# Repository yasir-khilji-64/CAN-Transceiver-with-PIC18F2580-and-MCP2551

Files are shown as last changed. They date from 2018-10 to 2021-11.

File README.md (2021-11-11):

# CAN Transceiver with PIC18F2580 and MCP2551

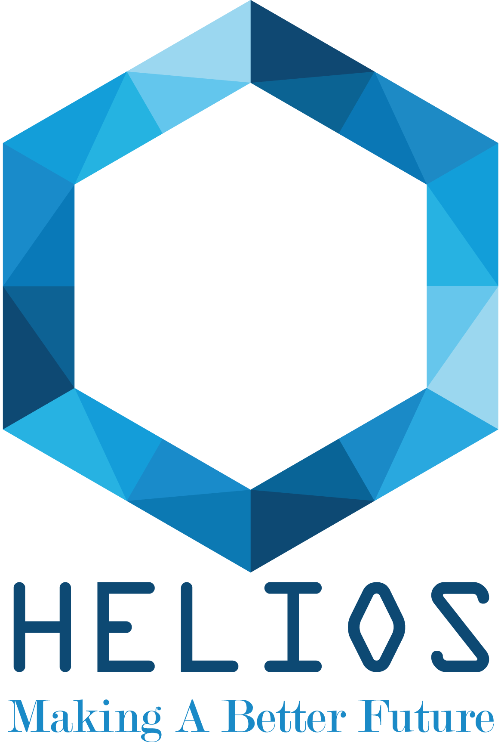
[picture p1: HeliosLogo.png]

<h2 align="center"><strong>Developed by Helios LLC</strong></h2>

## Development
Current version is **v2.0**. The device uses **PIC18F25K80** as the base MCU. Other chips include **MCP2551 High-Speed CAN Transceiver**. Board is developed for students who are learning Electronics Design and PCB Design. 

---
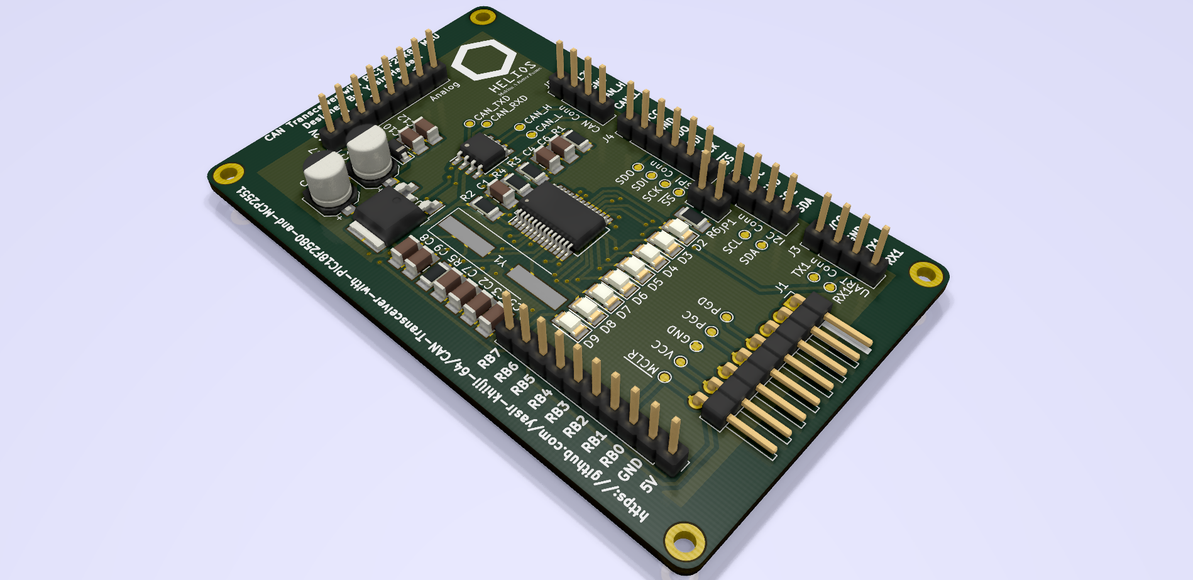
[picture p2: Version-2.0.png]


## Built With
* [KiCad 5.0](http://kicad.org) - PCB Design Tool

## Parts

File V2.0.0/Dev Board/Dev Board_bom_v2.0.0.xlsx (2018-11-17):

Component | Description | Part | References | Value | Footprint | Quantity Per PCB | Quantity Per Board | Price | Datasheet | Supplier-I Part # | Mfr | Mfr Part # | Supplier-I
1 | Unpolarized capacitor | C | C1 C2 C3 C5 C10 C12 | 100nF | C_1206_3216Metric_Pad1.39x1.80mm_HandSolder | 6 | 120 | SEK 386.40 | ~ | 2332842 | AVX | 12061C104JAT2A | Farnell
2 | Polarised capacitor | CP | C11 C13 | 100uF | CP_Elec_5x5.9 | 2 | 40 | SEK 158.80 | ~ | 2065969 | Panasonic Electronic Components | EEE-FT1C101AR | Farnell
3 | Unpolarized capacitor | C | C7 | 10uF | C_1206_3216Metric_Pad1.39x1.80mm_HandSolder | 1 | 20 | SEK 91.20 | ~ | 3188954 | Yageo | CC1206ZRY5V6BB106 | Farnell
4 | Unpolarized capacitor | C | C8 C9 | 22pF | C_1206_3216Metric_Pad1.39x1.80mm_HandSolder | 2 | 40 | SEK 52.00 | ~ | 2812188 | Wurth Electronics Inc. | 885012008011 | Farnell
5 | Unpolarized capacitor | C | C4 C6 | 560pF | C_1206_3216Metric_Pad1.39x1.80mm_HandSolder | 2 | 40 | SEK 101.60 | ~ | 2211027 | Yageo | CC1206JKNPOZBN561 | Farnell
6 | LED generic | LED | D2 D3 D4 D5 D6 D7 D8 D9 | Green | LED_1206_3216Metric_Pad1.22x1.80mm_HandSolder | 8 | 160 | SEK 241.60 | ~ | 8554595 | BROADCOM LIMITED | HSMG-C150. | Farnell
7 | Schottky diode | D_Schottky | D1 | MBR0530 | D_SOD-123 | 1 | 20 | SEK 50.60 | ~ | 2463401 | ON SEMICONDUCTOR | MBR0530 | Farnell
8 | Generic connector, single row, 01x08, script generated (kicad-library-utils/schlib/autogen/connector/) | Conn_01x08 | J7 | Analog | PinHeader_1x08_P2.54mm_Vertical | 1 | 20 | SEK 67.80 | ~ | 2356160 | WURTH ELEKTRONIK | 61300811121 | Farnell
9 | Generic connector, single row, 01x04, script generated (kicad-library-utils/schlib/autogen/connector/) | Conn_01x04 | J5 | CAN Conn | PinHeader_1x04_P2.54mm_Vertical | 1 | 20 | SEK 22.00 | ~ | 1022250 | HARWIN | M20-9990445 | Farnell
10 | Generic connector, single row, 01x04, script generated (kicad-library-utils/schlib/autogen/connector/) | Conn_01x04 | J2 | I2C Conn | PinHeader_1x04_P2.54mm_Vertical | 1 | 20 | SEK 22.00 | ~ | 1022250 | HARWIN | M20-9990445 | Farnell
11 | Generic connector, single row, 01x08, script generated (kicad-library-utils/schlib/autogen/connector/) | Conn_01x08 | J1 | PICKIT4 Conn | PinHeader_1x08_P2.54mm_Horizontal | 1 | 20 | SEK 142.60 | ~ | 2356183 | WURTH ELEKTRONIK | 61300811021 | Farnell
12 | Generic connector, single row, 01x10, script generated (kicad-library-utils/schlib/autogen/connector/) | Conn_01x10 | J6 | PORT B | PinHeader_1x10_P2.54mm_Vertical | 1 | 20 | SEK 166.80 | ~ | 1841229 | WURTH ELEKTRONIK | 61301011121 | Farnell
13 | Generic connector, single row, 01x06, script generated (kicad-library-utils/schlib/autogen/connector/) | Conn_01x06 | J4 | SPI Conn | PinHeader_1x06_P2.54mm_Vertical | 1 | 20 | SEK 61.20 | ~ | 2356158 | WURTH ELEKTRONIK | 61300611121 | Farnell
14 | Generic connector, single row, 01x04, script generated (kicad-library-utils/schlib/autogen/connector/) | Conn_01x04 | J3 | UART Conn | PinHeader_1x04_P2.54mm_Vertical | 1 | 20 | SEK 22.00 | ~ | 1022250 | HARWIN | M20-9990445 | Farnell
15 | Jumper, normally closed | Jumper_NC_Small | JP1 | JP_LED | PinHeader_1x02_P2.54mm_Vertical | 1 | 20 | SEK 26.40 | ~ | 9731075 | MOLEX | 22-03-2021 | Farnell
16 | Resistor | R | R3 R4 | 100 | R_1206_3216Metric_Pad1.39x1.80mm_HandSolder | 2 | 40 | SEK 28.48 | ~ | 9240888 | Yageo | RC1206FR-07100RL | Farnell
17 | Resistor | R | R2 | 10k | R_1206_3216Metric_Pad1.39x1.80mm_HandSolder | 1 | 20 | SEK 274.80 | ~ | 1653333 | VISHAY | TNPW120610K0BEEA | Farnell
18 | Resistor | R | R5 | 1M | R_1206_3216Metric_Pad1.39x1.80mm_HandSolder | 1 | 20 | SEK 8.68 | ~ | 1469968 | VISHAY | CRCW12061M00FKEA | Farnell
19 | Resistor | R | R6 | 330 | R_1206_3216Metric_Pad1.39x1.80mm_HandSolder | 1 | 20 | SEK 16.76 | ~ | 9240918 | Yageo | RC1206FR-07330RL | Farnell
20 | Resistor | R | R1 | 4.7k | R_1206_3216Metric_Pad1.39x1.80mm_HandSolder | 1 | 20 | SEK 42.20 | ~ | 2470962 | Bourns Inc. | CRS1206-FX-4701ELF | Farnell
21 | High-Speed CAN Transceiver, 1Mbps, 5V supply, SOIC8 package | MCP2551-I-SN | U1 | MCP2551-I-SN | SOIC-8_3.9x4.9mm_P1.27mm | 1 | 20 | SEK 183.80 | http://ww1.microchip.com/downloads/en/devicedoc/21667d.pdf | 9758569 | Microchip Technology | MCP2551-I/SN | Farnell
22 | 1A Low drop-out regulator, Fixed Output 12V, TO-252 (DPAK) | NCP1117-5.0_TO252 | U3 | NCP1117-5.0_TO252 | TO-252-2 | 1 | 20 | SEK 68.60 | http://www.onsemi.com/pub_link/Collateral/NCP1117-D.PDF | 2296057 | ON SEMICONDUCTOR | NCP1117DT50G | Farnell
23 | 32K Flash, 3.5K RAM, 1K EEPROM, PIC18 Microcontroller ADC PWM CAN SPI I2C USART in SSOP28 package | PIC18F25K80_ISS | U2 | PIC18F25K80_ISS | SSOP-28_5.3x10.2mm_P0.65mm | 1 | 20 | SEK 890.60 | http://ww1.microchip.com/downloads/en/DeviceDoc/39977f.pdf | 9321284 | Microchip Technology | PIC18F2580-I/SO | Farnell
24 | Two pin crystal | Crystal | Y1 | 20MHz | Crystal_SMD_HC49-SD_HandSoldering | 1 | 20 | SEK 59.20 | ~ | 2467724 | Abracon LLC | ABLS-20.000MHZ-B2-T | Farnell
25 | Jumper | - | - | - | - | 1 | 20 | SEK 64.00 | - | 1822046 | TE CONNECTIVITY | 827914-1 | Farnell
Component Groups: | 24
Component Count: | 41
Fitted Components: | 40
Number of PCBs: | 20
Total components: | 40
Schematic Version: | v2.0.0
Schematic Date: | 2018-10-30
BoM Date: | 2018-11-06 01:54
KiCad Version: | Eeschema (5.0.0)
Prince in SEK: | SEK 3250.12
Prince in USD | USD 360.76

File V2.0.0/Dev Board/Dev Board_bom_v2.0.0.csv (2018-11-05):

Component | Description | Part | References | Value | Footprint | Quantity Per PCB | Datasheet | Supplier-I Part # | Mfr | Mfr Part # | Supplier-I | Nfr Part #
1 | Unpolarized capacitor | C | C1 C2 C3 C5 C10 C12 | 100nF | C_1206_3216Metric_Pad1.39x1.80mm_HandSolder | 6 | ~ | 2332842 | AVX | 12061C104JAT2A | Farnell
2 | Polarised capacitor | CP | C11 C13 | 100uF | CP_Elec_5x5.9 | 2 | ~ | 2065969 | Panasonic Electronic Components | EEE-FT1C101AR | Farnell
3 | Unpolarized capacitor | C | C7 | 10uF | C_1206_3216Metric_Pad1.39x1.80mm_HandSolder | 1 | ~ | 3188954 | Yageo | CC1206ZRY5V6BB106 | Farnell
4 | Unpolarized capacitor | C | C8 C9 | 22pF | C_1206_3216Metric_Pad1.39x1.80mm_HandSolder | 2 | ~ | 2812188 | Wurth Electronics Inc. | 885012008011 | Farnell
5 | Unpolarized capacitor | C | C4 C6 | 560pF | C_1206_3216Metric_Pad1.39x1.80mm_HandSolder | 2 | ~ | 2211027 | Yageo | CC1206JKNPOZBN561 | Farnell
6 | LED generic | LED | D2 D3 D4 D5 D6 D7 D8 D9 | Green | LED_1206_3216Metric_Pad1.22x1.80mm_HandSolder | 8 | ~ | 8554595 | BROADCOM LIMITED | HSMG-C150. | Farnell
7 | Schottky diode | D_Schottky | D1 | MBR0530 | D_SOD-123 | 1 | ~ | 2463401 | ON SEMICONDUCTOR | MBR0530 | Farnell
8 | Generic connector, single row, 01x08, script generated (kicad-library-utils/schlib/autogen/connector/) | Conn_01x08 | J7 | Analog | PinHeader_1x08_P2.54mm_Vertical | 1 | ~ | 2356160 | WURTH ELEKTRONIK | 61300811121 | Farnell
9 | Generic connector, single row, 01x04, script generated (kicad-library-utils/schlib/autogen/connector/) | Conn_01x04 | J5 | CAN Conn | PinHeader_1x04_P2.54mm_Vertical | 1 | ~ | 2356155 | WURTH ELEKTRONIK | 61300411121 | Farnell
10 | Generic connector, single row, 01x04, script generated (kicad-library-utils/schlib/autogen/connector/) | Conn_01x04 | J2 | I2C Conn | PinHeader_1x04_P2.54mm_Vertical | 1 | ~ | 2356155 | WURTH ELEKTRONIK | 61300411121 | Farnell
11 | Generic connector, single row, 01x08, script generated (kicad-library-utils/schlib/autogen/connector/) | Conn_01x08 | J1 | PICKIT4 Conn | PinHeader_1x08_P2.54mm_Horizontal | 1 | ~ | 2356183 | WURTH ELEKTRONIK | 61300811021 | Farnell
12 | Generic connector, single row, 01x10, script generated (kicad-library-utils/schlib/autogen/connector/) | Conn_01x10 | J6 | PORT B | PinHeader_1x10_P2.54mm_Vertical | 1 | ~ | 1841229 | WURTH ELEKTRONIK |  | Farnell | 61301011121
13 | Generic connector, single row, 01x06, script generated (kicad-library-utils/schlib/autogen/connector/) | Conn_01x06 | J4 | SPI Conn | PinHeader_1x06_P2.54mm_Vertical | 1 | ~ | 2356158 | WURTH ELEKTRONIK | 61300611121 | Farnell
14 | Generic connector, single row, 01x04, script generated (kicad-library-utils/schlib/autogen/connector/) | Conn_01x04 | J3 | UART Conn | PinHeader_1x04_P2.54mm_Vertical | 1 | ~ | 2356155 | WURTH ELEKTRONIK | 61300411121 | Farnell
15 | Jumper, normally closed | Jumper_NC_Small | JP1 | JP_LED | PinHeader_1x02_P2.54mm_Vertical | 1 | ~ | 9731075 | MOLEX | 22-03-2021 | Farnell
16 | Resistor | R | R3 R4 | 100 | R_1206_3216Metric_Pad1.39x1.80mm_HandSolder | 2 | ~ | 9240888 | Yageo | RC1206FR-07100RL | Farnell
17 | Resistor | R | R2 | 10k | R_1206_3216Metric_Pad1.39x1.80mm_HandSolder | 1 | ~ | 1653333 | VISHAY | TNPW120610K0BEEA | Farnell
18 | Resistor | R | R5 | 1M | R_1206_3216Metric_Pad1.39x1.80mm_HandSolder | 1 | ~ | 1469968 | VISHAY | CRCW12061M00FKEA | Farnell
19 | Resistor | R | R6 | 330 | R_1206_3216Metric_Pad1.39x1.80mm_HandSolder | 1 | ~ | 9240918 | Yageo | RC1206FR-07330RL | Farnell
20 | Resistor | R | R1 | 4.7k | R_1206_3216Metric_Pad1.39x1.80mm_HandSolder | 1 | ~ | 2470962 | Bourns Inc. | CRS1206-FX-4701ELF | Farnell
21 | High-Speed CAN Transceiver, 1Mbps, 5V supply, SOIC8 package | MCP2551-I-SN | U1 | MCP2551-I-SN | SOIC-8_3.9x4.9mm_P1.27mm | 1 | http://ww1.microchip.com/downloads/en/devicedoc/21667d.pdf | 9758569 | Microchip Technology | MCP2551-I/SN | Farnell
22 | 1A Low drop-out regulator, Fixed Output 12V, TO-252 (DPAK) | NCP1117-5.0_TO252 | U3 | NCP1117-5.0_TO252 | TO-252-2 | 1 | http://www.onsemi.com/pub_link/Collateral/NCP1117-D.PDF | 2296057 | ON SEMICONDUCTOR | NCP1117DT50G | Farnell
23 | 32K Flash, 3.5K RAM, 1K EEPROM, PIC18 Microcontroller ADC PWM CAN SPI I2C USART in SSOP28 package | PIC18F25K80_ISS | U2 | PIC18F25K80_ISS | SSOP-28_5.3x10.2mm_P0.65mm | 1 | http://ww1.microchip.com/downloads/en/DeviceDoc/39977f.pdf | 9321284 | Microchip Technology | PIC18F2580-I/SO | Farnell
24 | Two pin crystal | Crystal | Y1 | 20MHz | Crystal_SMD_HC49-SD_HandSoldering | 1 | ~ | 2467724 | Abracon LLC | ABLS-20.000MHZ-B2-T | Farnell
Component Groups: | 24
Component Count: | 40
Fitted Components: | 40
Number of PCBs: | 1
Total components: | 40
Schematic Version: | v2.0.0
Schematic Date: | 2018-10-30
BoM Date: | 11/6/2018 1:54:50 AM
Schematic Source: | C:\Personal\Work\Upwork\Raditex Control AB-PIC18F2580 and CAN Work\V2.0.0\Dev Board\Dev Board.sch
KiCad Version: | Eeschema (5.0.0)

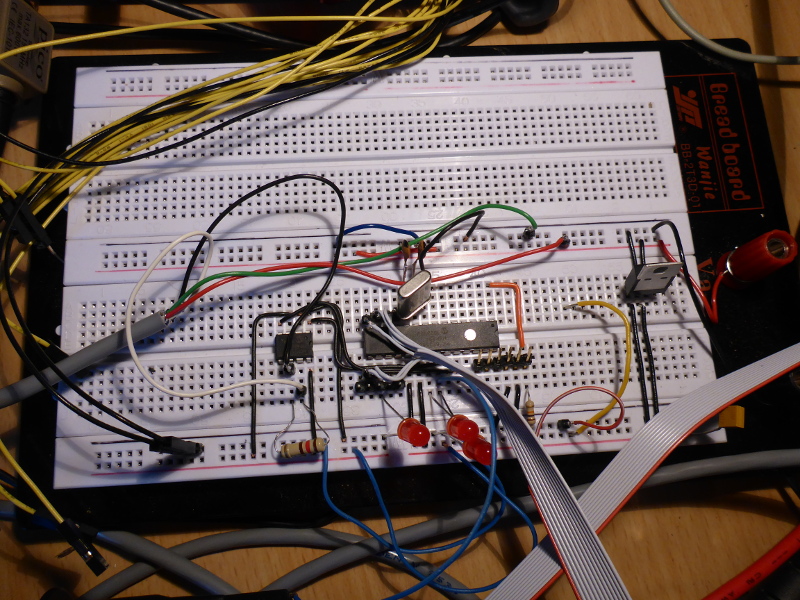
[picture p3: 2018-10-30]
Helping Material/pic-breadboard.jpg

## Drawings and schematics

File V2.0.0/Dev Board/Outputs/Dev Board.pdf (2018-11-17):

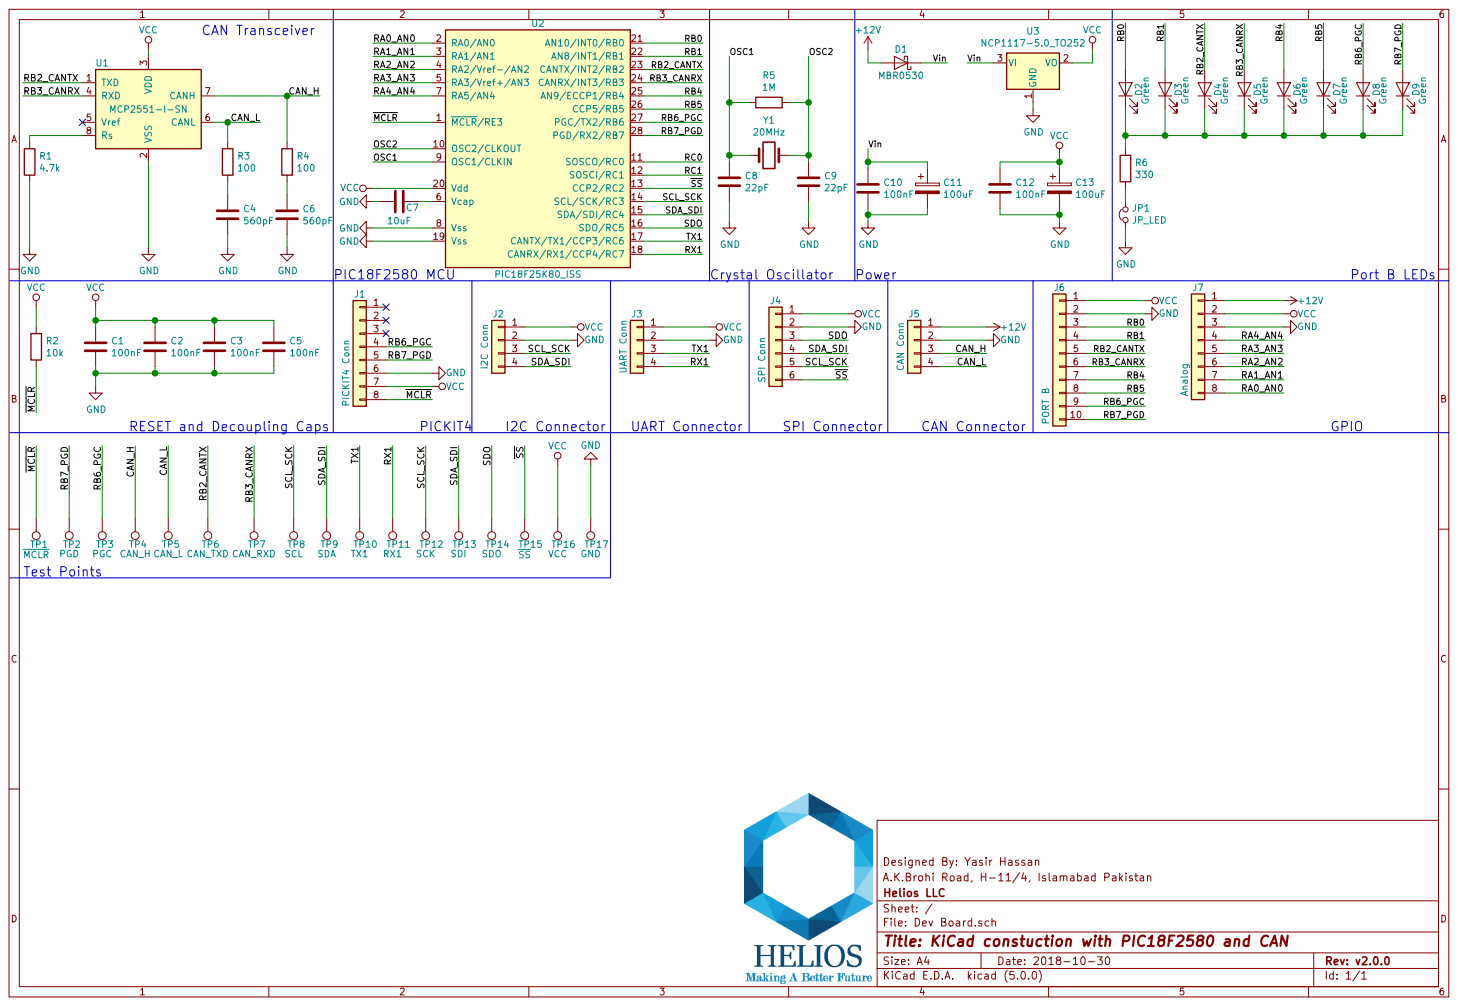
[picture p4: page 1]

1 VO 2 VI 3 U3 NCP1117-5.0_TO252 Vin VCC GND

3 RXD 4 Vref 5 CANL 6 CANH 7 Rs 8 U1 MCP2551-I-SN

Designed By: Yasir Hassan
A.K.Brohi Road, H-11/4, Islamabad Pakistan
File: Dev Board.sch Sheet: / Helios LLC

Id: 1/1 Title: KiCad constuction with PIC18F2580 and CAN

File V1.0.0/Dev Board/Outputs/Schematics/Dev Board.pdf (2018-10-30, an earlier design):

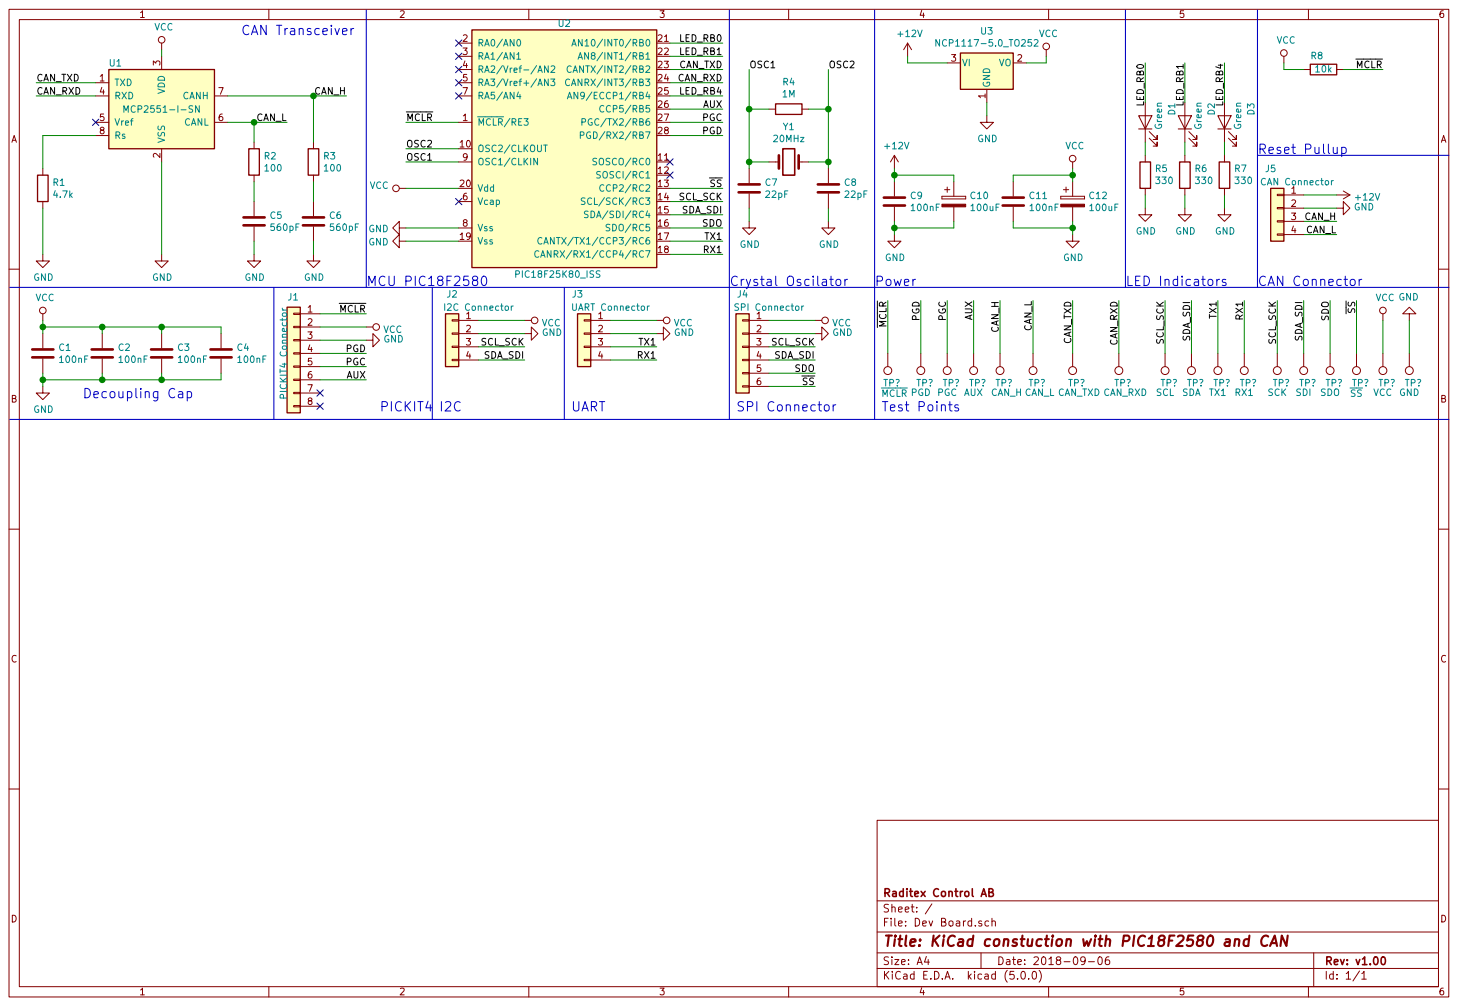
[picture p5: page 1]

3 RXD 4 Vref 5 CANL 6 CANH 7 Rs 8 U1 MCP2551-I-SN

TP? GND GND Test Points
TP? PGDPGD
TP? CAN_H CAN_H

File: Dev Board.sch Sheet: / Raditex Control AB

Id: 1/1 Title: KiCad constuction with PIC18F2580 and CAN

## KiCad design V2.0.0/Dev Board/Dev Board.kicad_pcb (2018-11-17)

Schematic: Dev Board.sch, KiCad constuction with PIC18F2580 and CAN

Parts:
C1, C2, C3, C5, C10, C12: 100nF; C_1206_3216Metric_Pad1.39x1.80mm_HandSolder; Mfr Part # 12061C104JAT2A
C4, C6: 560pF; C_1206_3216Metric_Pad1.39x1.80mm_HandSolder; Mfr Part # CC1206JKNPOZBN561
C7: 10uF; C_1206_3216Metric_Pad1.39x1.80mm_HandSolder; Mfr Part # CC1206ZRY5V6BB106
C8, C9: 22pF; C_1206_3216Metric_Pad1.39x1.80mm_HandSolder; Mfr Part # 885012008011
C11, C13: 100uF; CP_Elec_5x5.9; Mfr Part # EEE-FT1C101AR
D1: MBR0530; D_SOD-123; Mfr Part # MBR0530
D2, D3, D4, D5, D6, D7, D8, D9: Green; LED_1206_3216Metric_Pad1.22x1.80mm_HandSolder; Mfr Part # HSMG-C150.
J1: PICKIT4 Conn; PinHeader_1x08_P2.54mm_Horizontal; Mfr Part # 61300811021
J2: I2C Conn; PinHeader_1x04_P2.54mm_Vertical; Mfr Part # 61300411121
J3: UART Conn; PinHeader_1x04_P2.54mm_Vertical; Mfr Part # 61300411121
J4: SPI Conn; PinHeader_1x06_P2.54mm_Vertical; Mfr Part # 61300611121
J5: CAN Conn; PinHeader_1x04_P2.54mm_Vertical; Mfr Part # 61300411121
J6: PORT B; PinHeader_1x10_P2.54mm_Vertical
J7: Analog; PinHeader_1x08_P2.54mm_Vertical; Mfr Part # 61300811121
JP1: JP_LED; PinHeader_1x02_P2.54mm_Vertical; Mfr Part # 22-03-2021
R1: 4.7k; R_1206_3216Metric_Pad1.39x1.80mm_HandSolder; Mfr Part # CRS1206-FX-4701ELF
R2: 10k; R_1206_3216Metric_Pad1.39x1.80mm_HandSolder; Mfr Part # TNPW120610K0BEEA
R3, R4: 100; R_1206_3216Metric_Pad1.39x1.80mm_HandSolder; Mfr Part # RC1206FR-07100RL
R5: 1M; R_1206_3216Metric_Pad1.39x1.80mm_HandSolder; Mfr Part # CRCW12061M00FKEA
R6: 330; R_1206_3216Metric_Pad1.39x1.80mm_HandSolder; Mfr Part # RC1206FR-07330RL
TP1: ~MCLR; TestPoint_Pad_D1.0mm
TP2: PGD; TestPoint_Pad_D1.0mm
TP3: PGC; TestPoint_Pad_D1.0mm
TP4: CAN_H; TestPoint_Pad_D1.0mm
TP5: CAN_L; TestPoint_Pad_D1.0mm
TP6: CAN_TXD; TestPoint_Pad_D1.0mm
TP7: CAN_RXD; TestPoint_Pad_D1.0mm
TP8: SCL; TestPoint_Pad_D1.0mm
TP9: SDA; TestPoint_Pad_D1.0mm
TP10: TX1; TestPoint_Pad_D1.0mm
TP11: RX1; TestPoint_Pad_D1.0mm
TP12: SCK; TestPoint_Pad_D1.0mm
TP13: SDI; TestPoint_Pad_D1.0mm
TP14: SDO; TestPoint_Pad_D1.0mm
TP15: ~SS; TestPoint_Pad_D1.0mm
TP16: VCC; TestPoint_Pad_D1.0mm
TP17: GND; TestPoint_Pad_D1.0mm
U1: MCP2551-I-SN; SOIC-8_3.9x4.9mm_P1.27mm; Mfr Part # MCP2551-I/SN
U2: PIC18F25K80_ISS; SSOP-28_5.3x10.2mm_P0.65mm; Mfr Part # PIC18F2580-I/SO
U3: NCP1117-5.0_TO252; TO-252-2; Mfr Part # NCP1117DT50G
Y1: 20MHz; Crystal_SMD_HC49-SD_HandSoldering; Mfr Part # ABLS-20.000MHZ-B2-T

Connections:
+12V: D1.2, J5.1, J7.1
/CAN_H: J5.3, R4.1, TP4.1, U1.7
/CAN_L: J5.4, R3.1, TP5.1, U1.6
/OSC1: C8.1, R5.2, U2.9, Y1.1
/OSC2: C9.1, R5.1, U2.10, Y1.2
/RA0_AN0: J7.8, U2.2
/RA1_AN1: J7.7, U2.3
/RA2_AN2: J7.6, U2.4
/RA3_AN3: J7.5, U2.5
/RA4_AN4: J7.4, U2.7
/RB0: D2.2, J6.3, U2.21
/RB1: D3.2, J6.4, U2.22
/RB2_CANTX: D4.2, J6.5, TP6.1, U1.1, U2.23
/RB3_CANRX: D5.2, J6.6, TP7.1, U1.4, U2.24
/RB4: D6.2, J6.7, U2.25
/RB5: D7.2, J6.8, U2.26
/RB6_PGC: D8.2, J1.4, J6.9, TP3.1, U2.27
/RB7_PGD: D9.2, J1.5, J6.10, TP2.1, U2.28
/RC0: U2.11
/RC1: U2.12
/RX1: J3.4, TP11.1, U2.18
/SCL_SCK: J2.3, J4.5, TP8.1, TP12.1, U2.14
/SDA_SDI: J2.4, J4.4, TP9.1, TP13.1, U2.15
/SDO: J4.3, TP14.1, U2.16
/TX1: J3.3, TP10.1, U2.17
/Vin: C10.1, C11.1, D1.1, U3.3 (VI)
/~MCLR: J1.8, R2.2, TP1.1, U2.1
/~SS: J4.6, TP15.1, U2.13
GND: C1.2, C2.2, C3.2, C4.2, C5.2, C6.2, C7.1, C8.2, C9.2, C10.2, C11.2, C12.2, C13.2, J1.6, J2.2, J3.2, J4.2, J5.2, J6.2, J7.3, JP1.1, R1.2, TP17.1, U1.2, U2.8, U2.19, U3.1 (GND)
unnamed: C4.1, R3.2
unnamed: C6.1, R4.2
unnamed: C7.2, U2.6
unnamed: D2.1, D3.1, D4.1, D5.1, D6.1, D7.1, D8.1, D9.1, R6.1
unnamed: JP1.2, R6.2
unnamed: R1.1, U1.8
VCC: C1.1, C2.1, C3.1, C5.1, C12.1, C13.1, J1.7, J2.1, J3.1, J4.1, J6.1, J7.2, R2.1, TP16.1, U1.3, U2.20, U3.2 (VO)

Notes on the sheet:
CAN Transceiver
PIC18F2580 MCU
Crystal Oscillator
Power
Port B LEDs
RESET and Decoupling Caps
PICKIT4
Test Points
I2C Connector
UART Connector
SPI Connector
CAN Connector
GPIO

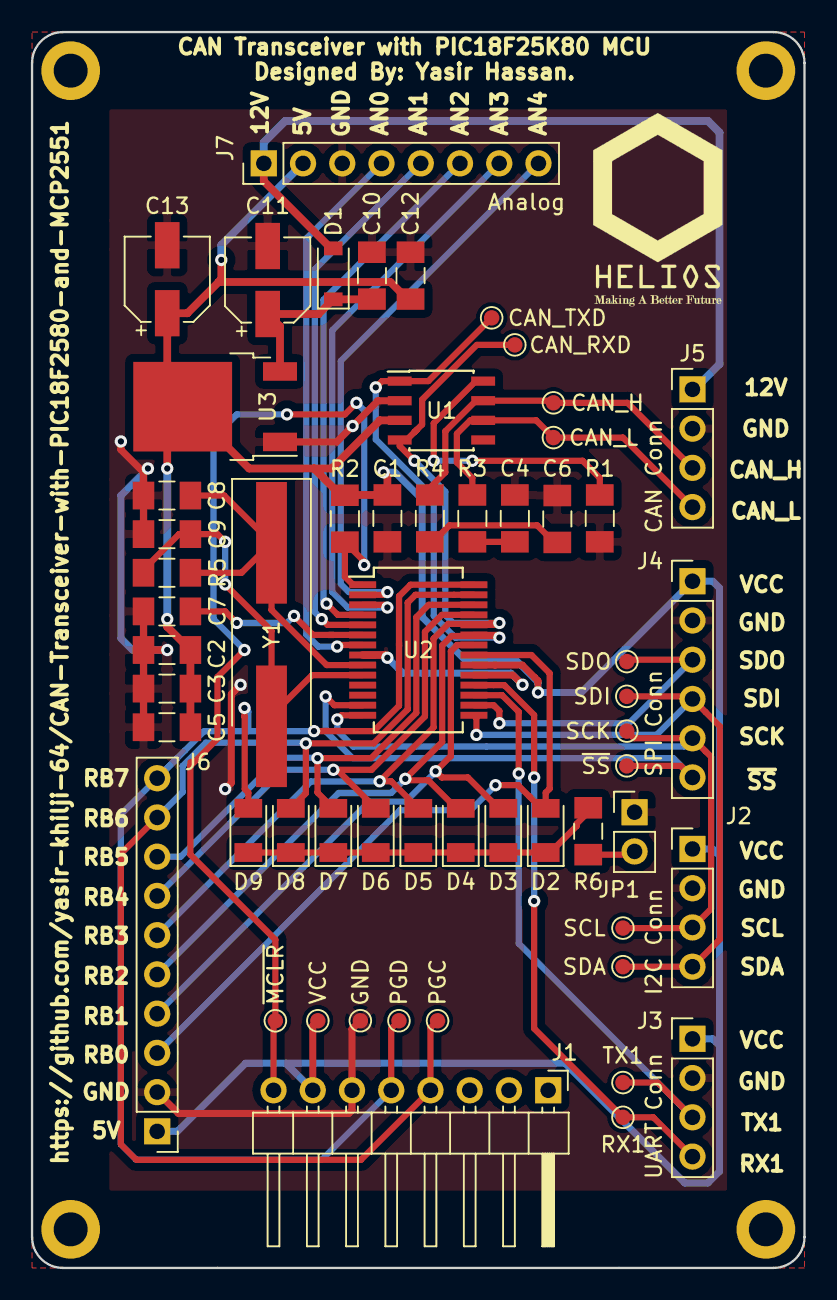
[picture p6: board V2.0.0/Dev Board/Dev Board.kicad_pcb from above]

Board: 2 copper layers, 50.0 x 80.0 mm, 57 parts (0 on the bottom side), 34 nets.

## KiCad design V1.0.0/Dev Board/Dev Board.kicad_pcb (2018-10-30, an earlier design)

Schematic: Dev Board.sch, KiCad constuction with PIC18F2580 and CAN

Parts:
C1, C2, C3, C4, C9, C11: 100nF; C_1206_3216Metric_Pad1.39x1.80mm_HandSolder; Mfr Part # GRM31A5C2J101JW01D
C5, C6: 560pF; C_1206_3216Metric_Pad1.39x1.80mm_HandSolder; Mfr Part # CC1206JKNPOZBN561
C7, C8: 22pF; C_1206_3216Metric_Pad1.39x1.80mm_HandSolder; Mfr Part # 885012008011
C10, C12: 100uF; CP_Elec_5x5.9; Mfr Part # EEE-FT1C101AR
C13: 10uF; C_1206_3216Metric_Pad1.39x1.80mm_HandSolder; Mfr Part # CC1206ZRY5V6BB106
D1, D2, D3: Green; LED_1206_3216Metric_Pad1.22x1.80mm_HandSolder; Mfr Part # LTST-C150GKT
D4: MBR0530; D_SOD-123; Mfr Part # MBR0530
J1: PICKIT4 Conn; PinHeader_1x08_P2.54mm_Vertical; Mfr Part # 61300811121
J2: I2C Conn; PinHeader_1x04_P2.54mm_Vertical; Mfr Part # 61300411121
J3: UART Conn; PinHeader_1x04_P2.54mm_Vertical; Mfr Part # 61300411121
J4: SPI Conn; PinHeader_1x06_P2.54mm_Vertical; Mfr Part # 61300611121
J5: CAN Conn; PinHeader_1x04_P2.54mm_Vertical; Mfr Part # 61300411121
J6: GPIO; PinHeader_1x10_P2.54mm_Vertical; Mfr Part # 61301011121
R1: 4.7k; R_1206_3216Metric_Pad1.39x1.80mm_HandSolder; Mfr Part # CRS1206-FX-4701ELF
R2, R3: 100; R_1206_3216Metric_Pad1.39x1.80mm_HandSolder; Mfr Part # RC1206FR-07100RL
R4: 1M; R_1206_3216Metric_Pad1.39x1.80mm_HandSolder; Mfr Part # AC1206FR-071ML
R5, R6, R7: 330; R_1206_3216Metric_Pad1.39x1.80mm_HandSolder; Mfr Part # RC1206FR-07330RL
R8: 10k; R_1206_3216Metric_Pad1.39x1.80mm_HandSolder; Mfr Part # RT1206BRD0710KL
TP1: ~MCLR~; TestPoint_Pad_D1.0mm
TP2: PGD; TestPoint_Pad_D1.0mm
TP3: PGC; TestPoint_Pad_D1.0mm
TP5: CAN_H; TestPoint_Pad_D1.0mm
TP6: CAN_L; TestPoint_Pad_D1.0mm
TP7: CAN_TXD; TestPoint_Pad_D1.0mm
TP8: CAN_RXD; TestPoint_Pad_D1.0mm
TP9: SCL; TestPoint_Pad_D1.0mm
TP10: SDA; TestPoint_Pad_D1.0mm
TP11: TX1; TestPoint_Pad_D1.0mm
TP12: RX1; TestPoint_Pad_D1.0mm
TP13: SCK; TestPoint_Pad_D1.0mm
TP14: SDI; TestPoint_Pad_D1.0mm
TP15: SDO; TestPoint_Pad_D1.0mm
TP16: ~SS~; TestPoint_Pad_D1.0mm
TP17: VCC; TestPoint_Pad_D1.0mm
TP18: GND; TestPoint_Pad_D1.0mm
U1: MCP2551-I-SN; SOIC-8_3.9x4.9mm_P1.27mm; Mfr Part # MCP2551-I/SN
U2: PIC18F25K80_ISS; SSOP-28_5.3x10.2mm_P0.65mm; Mfr Part # PIC18F2580-I/SO
U3: NCP1117-5.0_TO252; TO-252-2; Mfr Part # NCP1117DT50G
Y1: 20MHz; Crystal_SMD_HC49-SD_HandSoldering; Mfr Part # ABLS-20.000MHZ-B2-T

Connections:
+12V: D4.2, J5.1
/AN0: J6.4, U2.2
/AN1: J6.5, U2.3
/AN2: J6.6, U2.4
/AN3: J6.7, U2.5
/AN4: J6.8, U2.7
/CAN_H: J5.3, R3.1, TP5.1, U1.7
/CAN_L: J5.4, R2.1, TP6.1, U1.6
/CAN_RXD: TP8.1, U1.4, U2.24
/CAN_TXD: TP7.1, U1.1, U2.23
/LED_RB0: D1.2, J6.1, U2.21
/LED_RB1: D2.2, J6.2, U2.22
/LED_RB4: D3.2, J6.3, U2.25
/OSC1: C7.1, R4.2, U2.9, Y1.1
/OSC2: C8.1, R4.1, U2.10, Y1.2
/PGC: J1.5, TP3.1, U2.27
/PGD: J1.4, TP2.1, U2.28
/RX1: J3.4, TP12.1, U2.18
/SCL_SCK: J2.3, J4.3, TP9.1, TP13.1, U2.14
/SDA_SDI: J2.4, J4.4, TP10.1, TP14.1, U2.15
/SDO: J4.5, TP15.1, U2.16
/TX1: J3.3, TP11.1, U2.17
/Vin: C9.1, C10.1, D4.1, U3.3 (VI)
/~MCLR~: J1.1, R8.2, TP1.1, U2.1
/~SS~: J4.6, TP16.1, U2.13
GND: C1.2, C2.2, C3.2, C4.2, C5.2, C6.2, C7.2, C8.2, C9.2, C10.2, C11.2, C12.2, C13.2, J1.3, J2.2, J3.2, J4.2, J5.2, J6.10, R1.2, R5.1, R6.1, R7.1, TP18.1, U1.2, U2.8, U2.19, U3.1 (GND)
unnamed: C5.1, R2.2
unnamed: C6.1, R3.2
unnamed: C13.1, U2.6
unnamed: D1.1, R5.2
unnamed: D2.1, R6.2
unnamed: D3.1, R7.2
unnamed: R1.1, U1.8
VCC: C1.1, C2.1, C3.1, C4.1, C11.1, C12.1, J1.2, J2.1, J3.1, J4.1, J6.9, R8.1, TP17.1, U1.3, U2.20, U3.2 (VO)

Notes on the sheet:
CAN Transceiver
MCU PIC18F2580
Crystal Oscilator
Power
LED Indicators
Decoupling Cap
Reset Pullup
CAN Connector
PICKIT4
I2C
UART
SPI Connector
Test Points
GPIOs

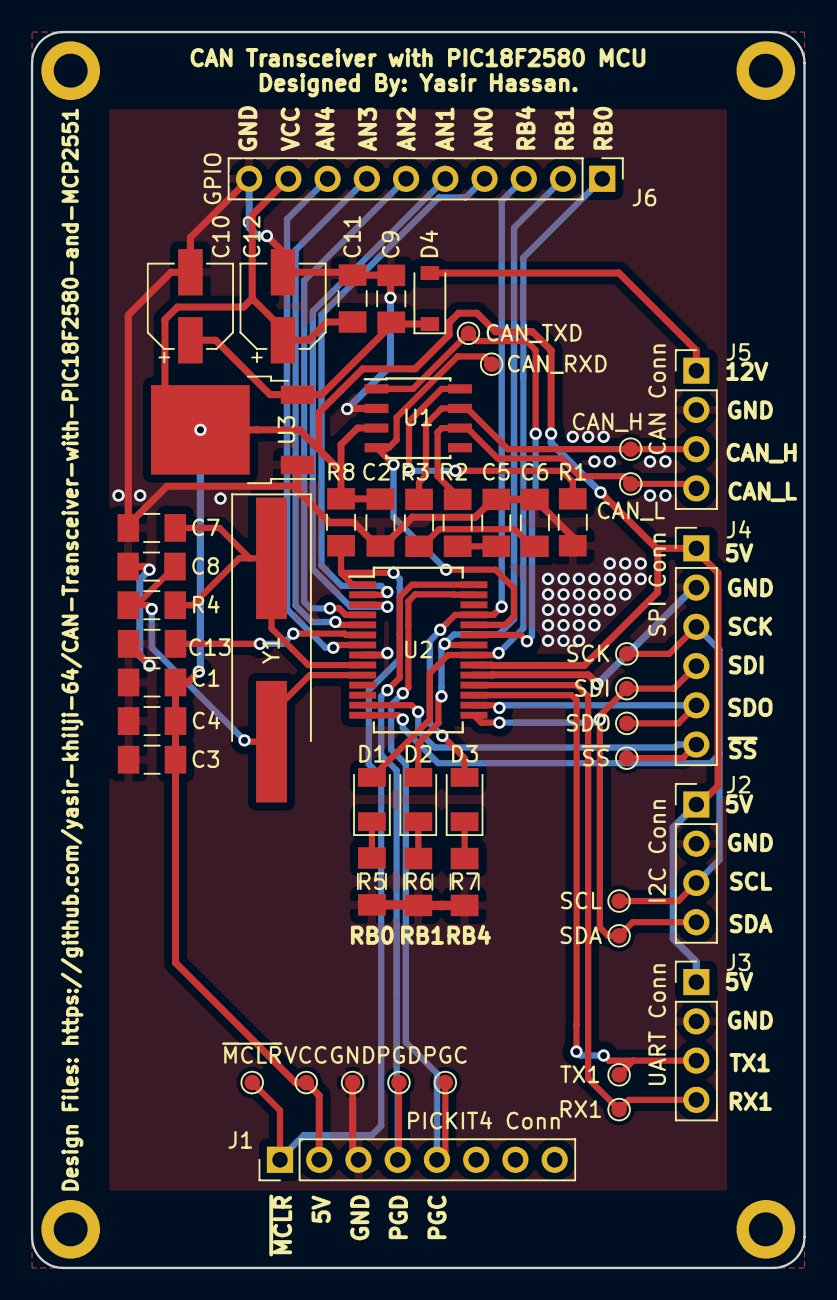
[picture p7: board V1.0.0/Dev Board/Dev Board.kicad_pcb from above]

Board: 2 copper layers, 50.0 x 80.0 mm, 52 parts (0 on the bottom side), 34 nets.

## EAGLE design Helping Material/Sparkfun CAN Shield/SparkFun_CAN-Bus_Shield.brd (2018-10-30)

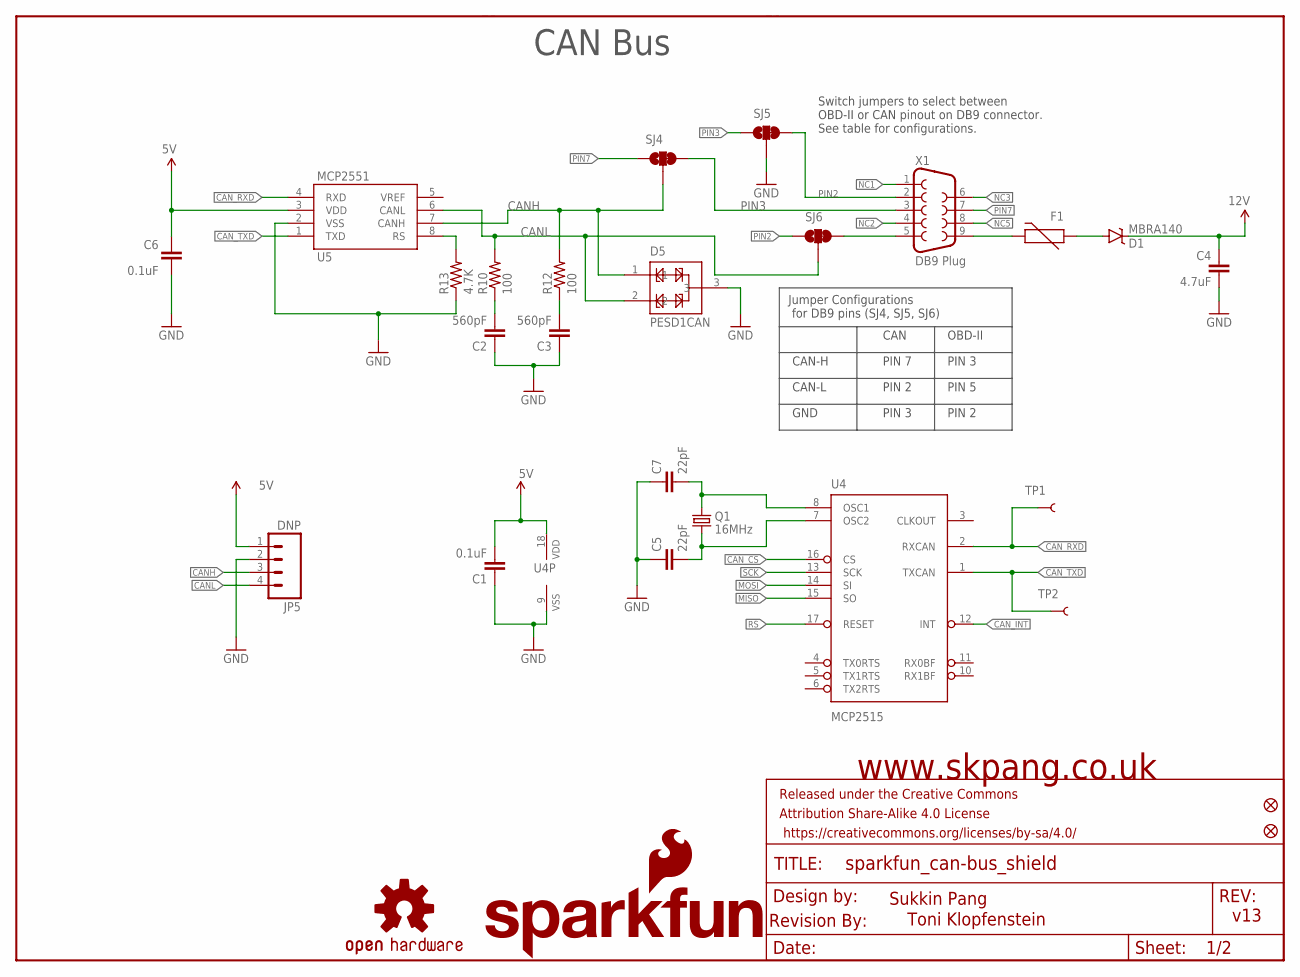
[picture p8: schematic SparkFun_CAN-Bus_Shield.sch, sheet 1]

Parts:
C1, C6: 0.1uF; 0603-CAP
C2, C3: 560pF; 0603-CAP
C4: 4.7uF; 0603-CAP
C5, C7: 22pF; 0603-CAP
D1: MBRA140; SMA-DIODE
D5: PESD1CAN; SOT23-3
F1: PTCTHERMISTOR1206; PTC-1206
FRAME1: FRAME-LETTER; CREATIVE_COMMONS
JP2, JP3: FIDUCIAL1X2; FIDUCIAL-1X2
JP4: SFE_LOGO_NAME_FLAME.1_INCH; SFE_LOGO_NAME_FLAME_.1
JP5: DNP; 1X04
LOGO1: OSHW-LOGOM; OSHW-LOGO-M
Q1: 16MHz; CRYSTAL-SMD-5X3
R10, R12: 100; 0603-RES
R13: 4.7K; 0603-RES
SJ4, SJ5, SJ6: JUMPER-PAD-3-2OF3_NC_BY_TRACE_SMALL; PAD-JUMPER-3-2OF3_NC_BY_TRACE_YES_SILK_FULL_BOX
TP1, TP2: TEST-POINT3X5; PAD.03X.05
U4: MCP2515; SO-18W
U5: MCP2551; SO08
U$1: REVISION
X1: DB9 Plug; DB9_MALE

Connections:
5V: C1.2, C6.2, JP5.1, U4.18 (VDD), U5.3 (VDD); also elsewhere on the board
12V: C4.1, D1.C; also elsewhere on the board
CANH: D5.1, JP5.3, R12.2, SJ4.2, U5.7 (CANH)
CANL: D5.2, JP5.4, R10.2, SJ6.2, U5.6 (CANL)
CAN_CS: U4.16 (CS); also elsewhere on the board
CAN_INT: U4.12 (INT); also elsewhere on the board
CAN_RXD: TP1.P$1, U4.2 (RXCAN), U5.4 (RXD)
CAN_TXD: TP2.P$1, U4.1 (TXCAN), U5.1 (TXD)
GND: C1.1, C2.1, C3.1, C4.2, C5.1, C6.1, C7.1, D5.3, JP5.2, R13.1, SJ5.2, U4.9 (VSS), U5.2 (VSS); also elsewhere on the board
MISO: U4.15 (SO); also elsewhere on the board
MOSI: U4.14 (SI); also elsewhere on the board
unnamed: SJ6.3, X1.5
unnamed: C2.2, R10.1
unnamed: C3.2, R12.1
unnamed: F1.2, X1.9
unnamed: R13.2, U5.8 (RS)
unnamed: D1.A, F1.1
unnamed: C7.2, Q1.3 (2), U4.8 (OSC1)
unnamed: C5.2, Q1.1, U4.7 (OSC2)
NC1: X1.1
NC2: X1.4
NC3: X1.6
NC5: X1.8
PIN2: SJ5.3, SJ6.1, X1.2
PIN3: SJ4.3, SJ5.1, X1.3
PIN7: SJ4.1, X1.7
RS: U4.17 (RESET); also elsewhere on the board
SCK: U4.13 (SCK); also elsewhere on the board

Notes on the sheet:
www.skpang.co.uk
Toni Klopfenstein
CAN Bus
CAN
OBD-II
CAN-H
CAN-L
GND
PIN 5
PIN 2
PIN 3
PIN 7
Jumper Configurations for DB9 pins (SJ4, SJ5, SJ6)
Switch jumpers to select between OBD-II or CAN pinout on DB9 connector. See table for configurations.
v13
Sukkin Pang

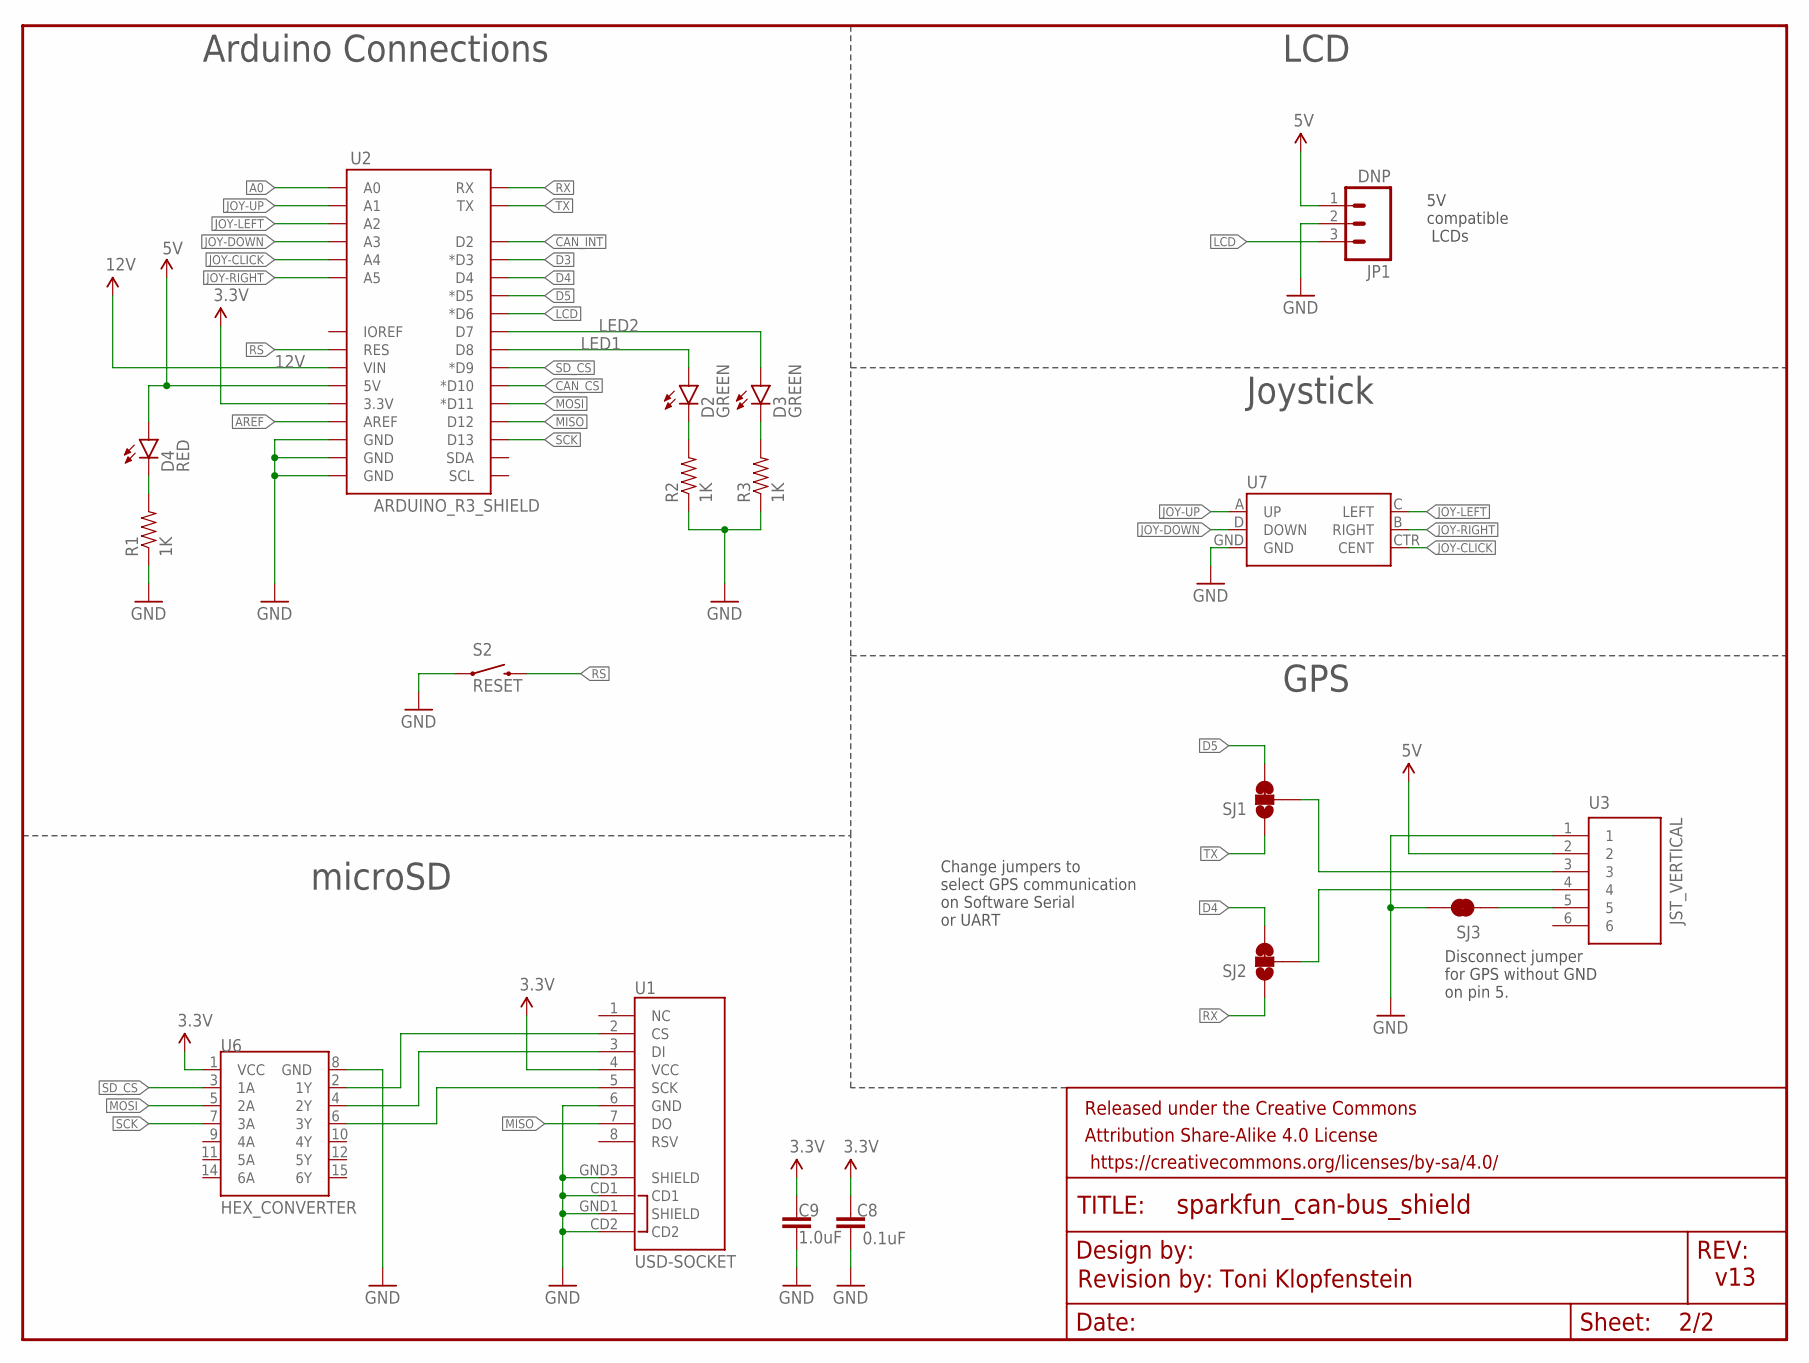
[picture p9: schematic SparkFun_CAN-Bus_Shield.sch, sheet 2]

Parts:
C8: 0.1uF; 0603-CAP
C9: 1.0uF; 0603-CAP
D2, D3: GREEN; LED-0603
D4: RED; LED-0603
FRAME2: FRAME-LETTERNO_PACKAGE; DUMMY
JP1: DNP; MOLEX-1X3_LOCK
R1, R2, R3: 1K; 0603-RES
S2: RESET; TACTILE-SWITCH-SMD
SJ1, SJ2: JUMPER-PAD-3-2OF3_NC_BY_TRACE_SMALL; PAD-JUMPER-3-2OF3_NC_BY_TRACE_YES_SILK_FULL_BOX
SJ3: JUMPER-PAD-2-NC_BY_TRACE; PAD-JUMPER-2-NC_BY_TRACE_YES_SILK
U1: USD-SOCKET; MICROSD_1:1
U2: ARDUINO_R3_SHIELD; UNO_R3_SHIELD
U3: JST_VERTICAL; JST-6-SMD-VERT-1.0MM
U6: HEX_CONVERTER; SO016
U7: JOYSTICK_MINI

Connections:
3.3V: C8.2, C9.1, U1.4 (VCC), U2.3.3V, U6.1 (VCC)
5V: D4.A, JP1.1, U2.5V, U3.2; also elsewhere on the board
12V: U2.VIN; also elsewhere on the board
A0: U2.A0
AREF: U2.AREF
CAN_CS: U2.D10 (*D10); also elsewhere on the board
CAN_INT: U2.D2; also elsewhere on the board
D3: U2.D3 (*D3)
D4: SJ2.3, U2.D4
D5: SJ1.3, U2.D5 (*D5)
GND: C8.1, C9.2, JP1.2, R1.1, R2.1, R3.1, S2.1, SJ3.2, U1.6 (GND), U1.CD1, U1.CD2, U1.GND1 (SHIELD), U1.GND3 (SHIELD), U2.GND@0 (GND), U2.GND@1 (GND), U2.GND@2 (GND), U3.1, U6.8 (GND), U7.GND; also elsewhere on the board
JOY-CLICK: U2.A4, U7.CTR (CENT)
JOY-DOWN: U2.A3, U7.D (DOWN)
JOY-LEFT: U2.A2, U7.C (LEFT)
JOY-RIGHT: U2.A5, U7.B (RIGHT)
JOY-UP: U2.A1, U7.A (UP)
LCD: JP1.3, U2.D6 (*D6)
LED1: D2.A, U2.D8
LED2: D3.A, U2.D7
MISO: U1.7 (DO), U2.D12; also elsewhere on the board
MOSI: U2.D11 (*D11), U6.5 (2A); also elsewhere on the board
unnamed: SJ3.1, U3.5
unnamed: D4.C, R1.2
unnamed: D2.C, R2.2
unnamed: D3.C, R3.2
unnamed: U1.2 (CS), U6.2 (1Y)
unnamed: U1.3 (DI), U6.4 (2Y)
unnamed: SJ1.2, U3.3
unnamed: SJ2.2, U3.4
unnamed: U1.5 (SCK), U6.6 (3Y)
RS: S2.3 (2), U2.RES; also elsewhere on the board
RX: SJ2.1, U2.RX
SCK: U2.D13, U6.7 (3A); also elsewhere on the board
SD_CS: U2.D9 (*D9), U6.3 (1A)
TX: SJ1.1, U2.TX

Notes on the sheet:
Arduino Connections
LCD
Joystick
5V compatible LCDs
GPS
Change jumpers to select GPS communication on Software Serial or UART
Disconnect jumper for GPS without GND on pin 5.
microSD
Revision by: Toni Klopfenstein
v13

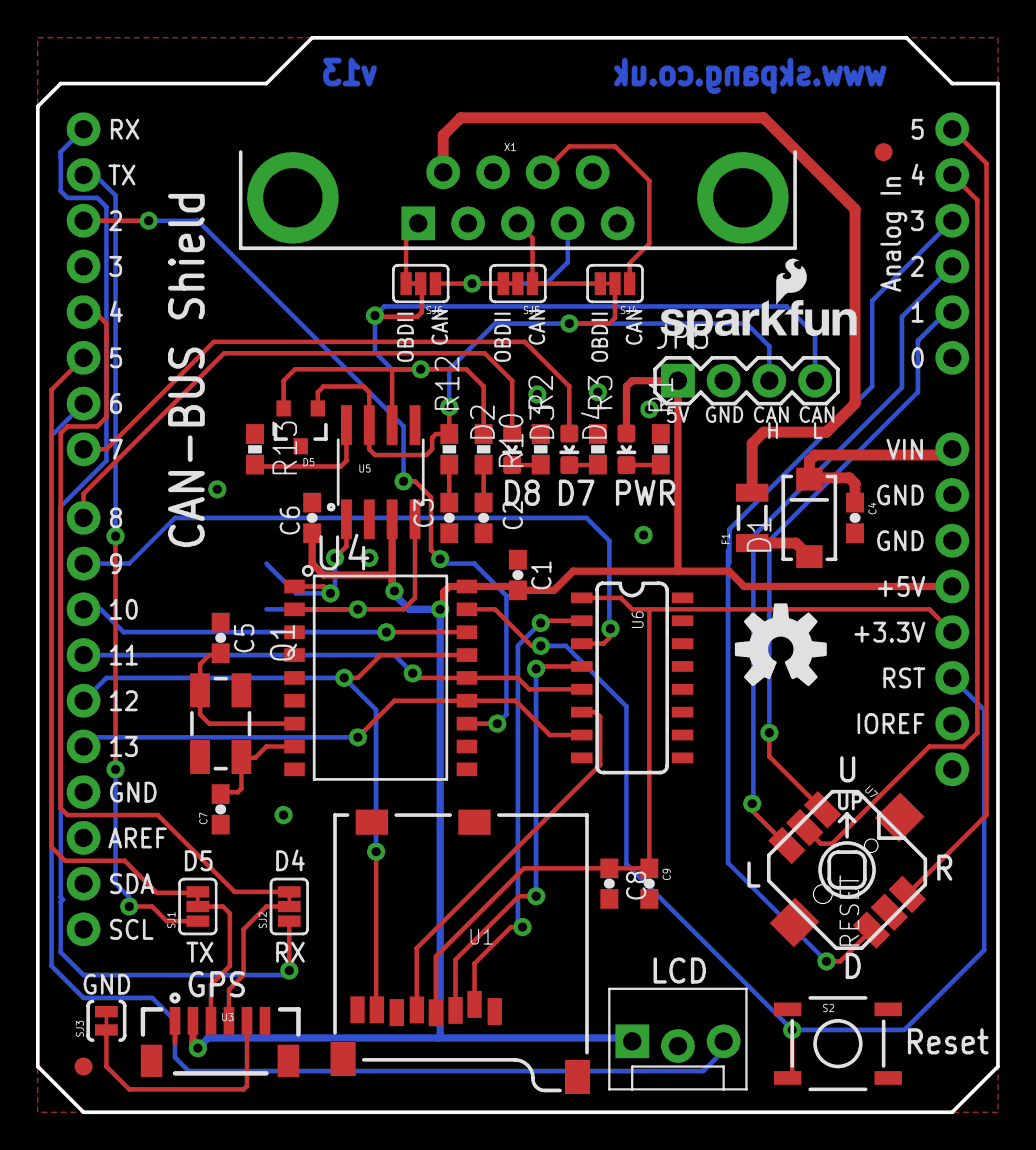
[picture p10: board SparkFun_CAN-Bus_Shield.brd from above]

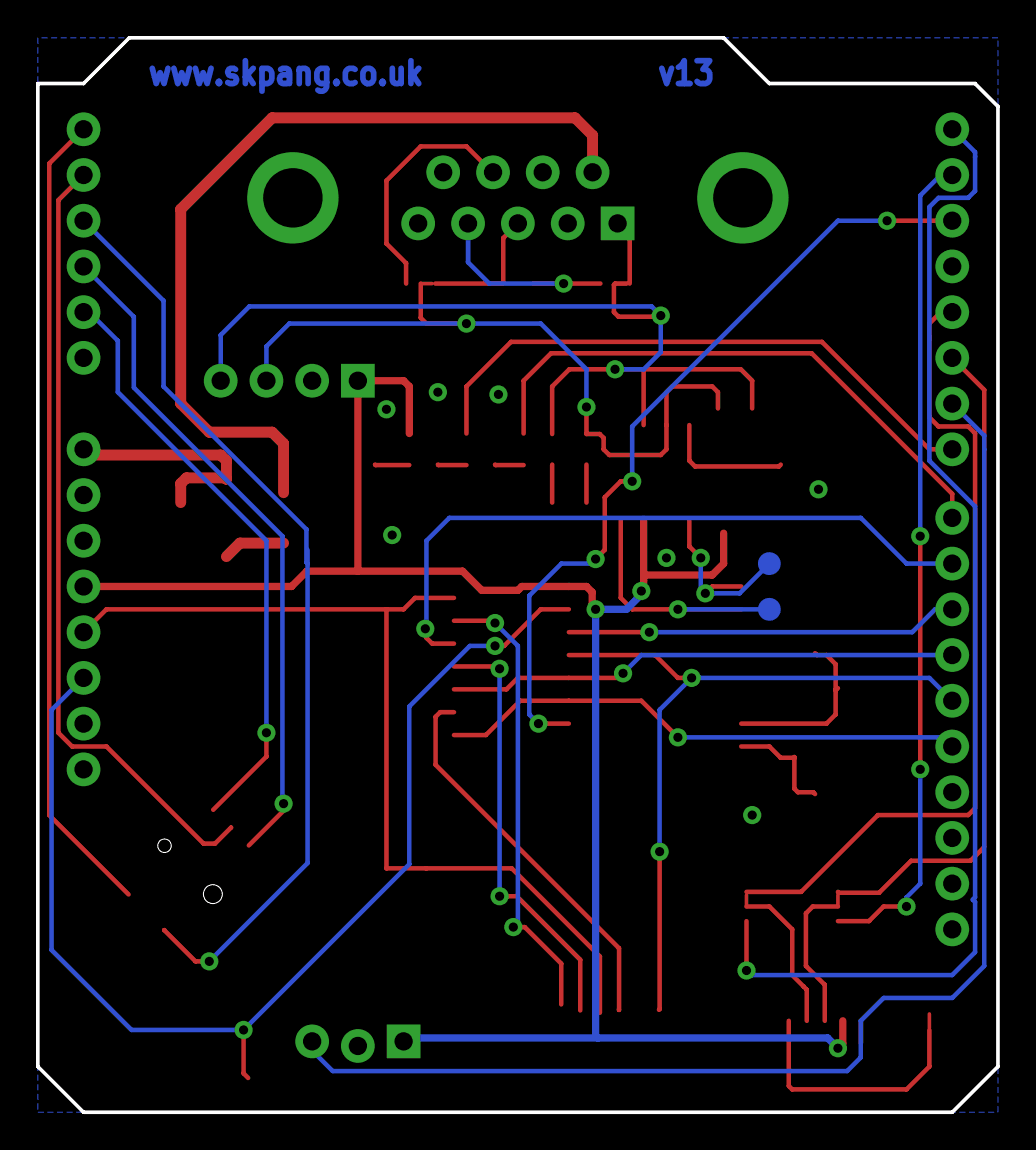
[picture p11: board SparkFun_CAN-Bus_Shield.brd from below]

Board: 2 copper layers, 53.3 x 59.7 mm, 48 parts (2 on the bottom side), 47 nets.

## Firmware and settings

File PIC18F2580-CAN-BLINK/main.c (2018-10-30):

/*
 * File:   main.c
 * Author: gorhas
 *
 * Created on den 15 augusti 2016, 20:54
 */

//#include <xc.h>


#include <xc.h>
#include "config.h"
//#include <p18f2580.h>
#include "ecan.h"

#define LEDPin LATAbits.LATA0 //Define LEDPin as PORT D Pin 1
#define LEDTris TRISAbits.TRISA0 //Define LEDTris as TRISD Pin 1

#define RELPin1 LATBbits.LATB4  //Define LEDPin as PORT D Pin 1
#define RELTris1 TRISBbits.TRISB4 // Define LEDTris as TRISD Pin 1

#define RELPin2 LATBbits.LATB5  //Define LEDPin as PORT D Pin 1
#define RELTris2 TRISBbits.TRISB5  //Define LEDTris as TRISD Pin 1


int varv = 200;

void delayzz(void)
{              
    int i, j;
   
    for(i=0;i<200;i++)
        {
        for(j=0;j<50;j++)
        {  ; /* Well its Just a Timer */ }
    }   
}

/*
void RunTimeInitialization(void)
{
    // Must be in Config mode to change many of settings.
    ECANSetOperationMode(ECAN_OP_MODE_CONFIG);

    // Select Mode 1
    ECANSetFunctionalMode(ECAN_MODE_1);


    // Make B0 as receiver.
    ECANSetBnTxRxMode(B0, ECAN_BUFFER_RX);

    // RXB0 will receive Stadard messages only.
    ECANSetRxBnRxMode(RXB0, ECAN_RECEIVE_ALL_VALID);

    // B0 will receive Extended
    ECANSetBnRxMode(B0, ECAN_RECEIVE_ALL_VALID);

    // Link RXF0 to RXB0 and RXF1 to B0
    ECANLinkRXF0F1ToBuffer(RXB0, B0);
    ECANLinkRXF0Thru3ToMask(ECAN_RXM0, ECAN_RXM1, ECAN_RXM0, ECAN_RXM0);

    ECANSetRXF0Value(0,         ECAN_MSG_STD);
    ECANSetRXF1Value(0,         ECAN_MSG_XTD);

    ECANSetRXM0Value(0,         ECAN_MSG_STD);
    ECANSetRXM1Value(0,         ECAN_MSG_XTD);

    // Set 125kbps @ 25MHz
    ECANSetBaudRate(2, 4, 8, 8, 8);

    // Return to Normal mode to communicate.
    ECANSetOperationMode(ECAN_OP_MODE_NORMAL);
}

*/

void main(void)
{
   int olle;

   char buffer[100];
   
   char sjw, brp, phseg1, phseg2, propseg;
   
   unsigned long id;
   
   BYTE data[4];
   BYTE dataLen;
   
   ECAN_RX_MSG_FLAGS flags;
  
   
   sjw = 3;
   brp = 8;
   phseg1 = 3;
   phseg2 = 3;
   propseg = 1;
   
   


   /*
   OSCTUNEbits.PLLEN = 1;
 
  OSCTUNEbits.TUN0 = 0;
  OSCTUNEbits.TUN1 = 0;
  OSCTUNEbits.TUN2 = 0;
  OSCTUNEbits.TUN3 = 0;
  OSCTUNEbits.TUN4 = 1;
  
   */
          
   data[0] = 0x40;
   data[1] = 0x55;
   data[2] = 0x40;
   data[3] = 0x55;

/*   
   OSCTUNEbits.PLLEN = 0;
   
   OSCTUNEbits.TUN0 = 1;
   OSCTUNEbits.TUN1 = 1;
   OSCTUNEbits.TUN2 = 1;
   OSCTUNEbits.TUN3 = 1;
   OSCTUNEbits.TUN4 = 0;
  
 */ 
   
   LEDTris = 0;//Set LED Pin data direction to OUTPUT
   LEDPin = 0;//Set LED Pin
   
   RELTris1 = 0;  //Set REL Pin data direction to OUTPUT
   RELPin1 = 0;   //Set REL Pin
 
   RELTris2 = 0;  //Set REL Pin data direction to OUTPUT
   RELPin2 = 0;   //Set REL Pin
    
   
   
   //ECANSetOperationMode(ECAN_OP_MODE_CONFIG);

   //ECANSetBaudRate(sjw, brp, phseg1, phseg2, propseg)
   //ECANSetBaudRate(2, 4, 8, 8, 8);

   //ECANSetOperationMode(ECAN_OP_MODE_NORMAL);

   //ECANSetOperationMode(ECAN_INIT_MODE);
      
   
   LEDPin = 0;
   
   ECANInitialize();
   
   data[0] = 0;
   
   while(1)
   {
        
      delayzz();
      
      data[0]++;
      
      LEDPin = ~LEDPin;
      
      //RELPin1 = ~RELPin1;
      //RELPin2 = ~RELPin2;
      
      
      //while( !ECANSendMessage(0x123, data, 4, ECAN_TX_STD_FRAME) );
      ECANSendMessage(0x42, data, 4, ECAN_TX_STD_FRAME);

     
      ECANReceiveMessage( &id,
                        data,
                        &dataLen,
                        &flags);
      
      //varv = data[1];

      if( id == 0x02)
      {
          
      while(data[0] != 0x00)
      {
        //LEDPin = ~LEDPin;
          
           LEDPin = 1;//Set LED Pin
           RELPin1 = 1;
           RELPin2 = 0;
           
          delayzz();
           LEDPin = 0;//Set LED Pin
           RELPin1 = 0;
           RELPin2 = 1;
           
          delayzz();

          data[0]--;
      
          ECANSendMessage(0x42, data, 4, ECAN_TX_STD_FRAME);
          
        }
      }
     
      
       
    //LEDPin = 0;//Set LED Pin
    
    id = 0x00;
    
    
      //data[0] = 0;
      
   
    }
   
    return;
}

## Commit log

2018-11-05 BOM Added
    [Dev Board_bom_v2.0.0.csv]
2018-11-17 PGD and PGC Glitch Removed
    [Dev Board-B.Cu.gbr, Dev Board-B.Mask.gbr, Dev Board-B.Paste.gbr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]
2021-11-10 Update README.md
    https://forum.kicad.info/t/warning-avoid-all-links-to-kicad-pcb-org-use-kicad-org/31521

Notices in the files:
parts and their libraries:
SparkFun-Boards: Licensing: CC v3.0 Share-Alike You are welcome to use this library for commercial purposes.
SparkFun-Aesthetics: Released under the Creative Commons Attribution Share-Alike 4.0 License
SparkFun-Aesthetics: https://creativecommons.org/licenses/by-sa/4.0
